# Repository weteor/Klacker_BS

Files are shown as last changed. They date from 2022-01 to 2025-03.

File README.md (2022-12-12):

# Klacker_BS
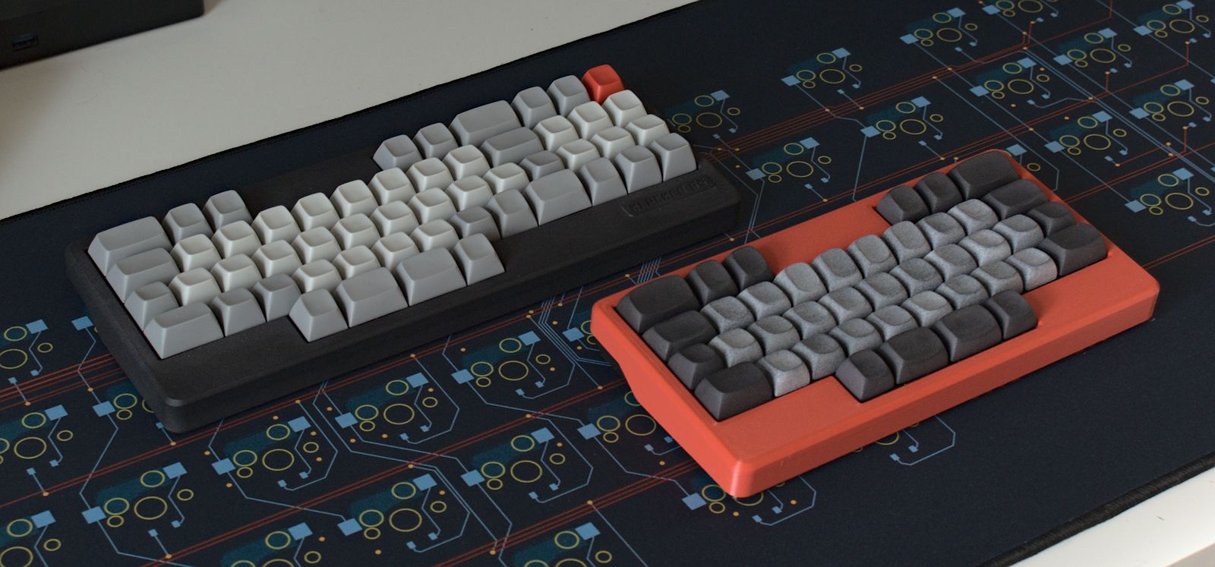
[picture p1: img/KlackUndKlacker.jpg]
klacker front


a 3x5+2 split keyboard hidden in a row staggered unibody design w/ numpad

## Features

- MX hotswap
- compact design
- layout for comfortable typing, straight wrist and minimal fingermovement
- reversable pcb w/ numpad breakoff - Layout options: Numpad Right, Left or None
- Bluetooth and USB connection 
- case files are supplied (stl, step, as well as freecad files)
- ZMK firmware support

## Layout
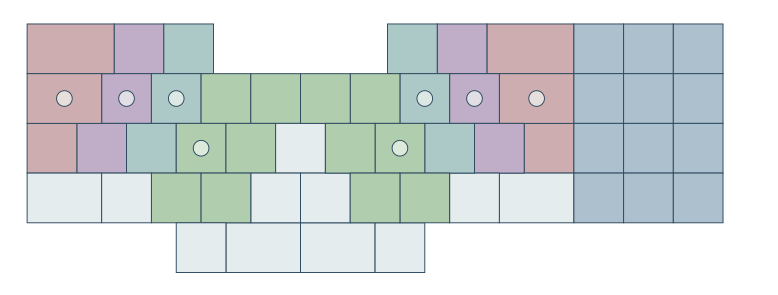
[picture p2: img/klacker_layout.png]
layout


Dots mark the home row. Colors indicate which finger is responsible for each key. It is essentially a 3x5+2 split and every keymap made for those will work on the Klacker. White keys except thumbs are free. I use the right ones as thumbkeys when I use the numpad.
It takes some time to adjust to the layout, but it is really comfortable to type on once the figers have adjusted.

## Want to build one?
You will find all production files needed to build your own [here](./prod).
I've included smt assembly files, but in the current times these might outdate quickly. If you can't figure out a replacement part, drop me a message and I will try to help out.

Case files can be found [here](./prod/case). The topside comes in two flavours. If you print at home with FDM printer, it might be better to use [prod/case/case_top_no_logo_FDM.stl](./prod/case/case_top_no_logo_FDM.stl). The top is completely flat and can be printed easily. If you use MJf or Resin use the other file

## cad data
Freecad source data for the case can be found [here](./cad_source). There are also step files if that's more helpful to you.
Plate can either be printed or made by your PCB manufacturer with the provided Kicad files.
Kicad data for plate and main pcb can be found [here](./pcb)

### firmware 
The Tipper TF uses ZMK firmware.

If you prefer the github workflow, you can find the zmk config for the Klacker BS [here](https://github.com/weteor/Klacker_BS-Config). 

## the rest
Everything in this repository is free to use however you might see fit. If you want to support me and my projects, please consider linking back to this repository if you build/change/use anything. 

If you would like to send me a tip, you could do it [here](https://ko-fi.com/weteor) (Please don't feel like you have to).

### pictures
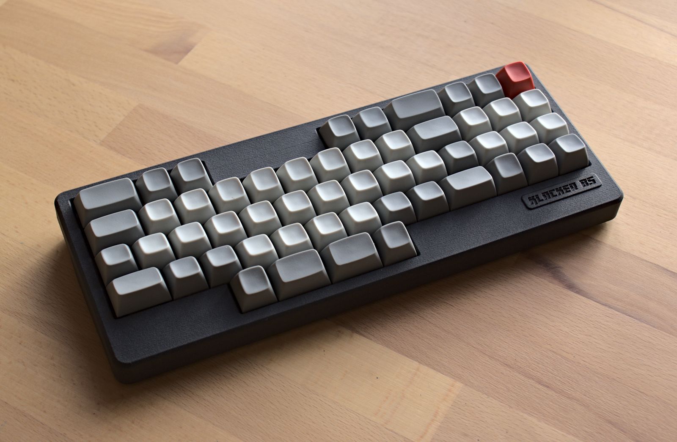
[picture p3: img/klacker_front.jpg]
klacker front

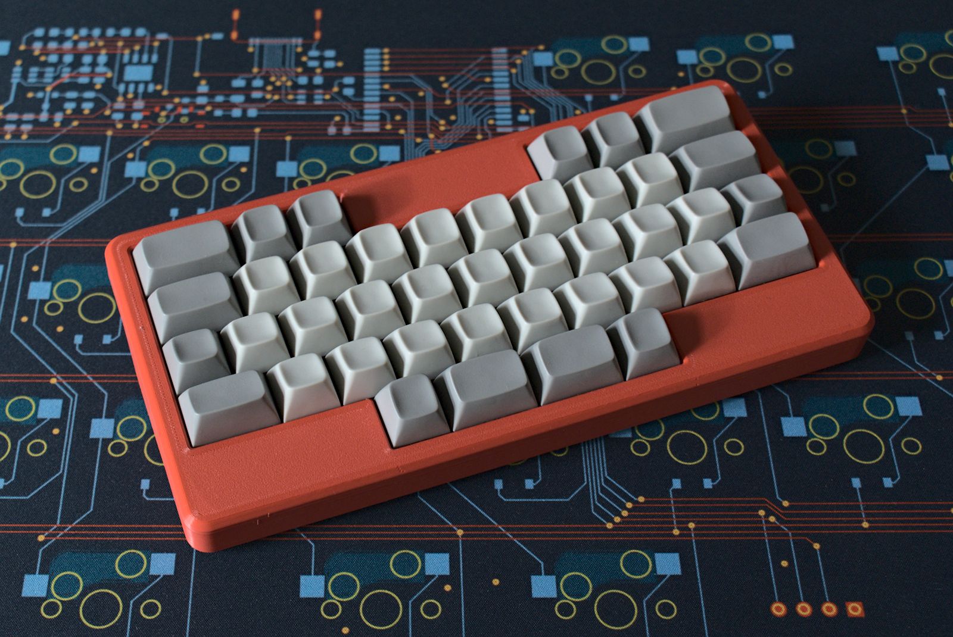
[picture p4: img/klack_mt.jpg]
klack mt

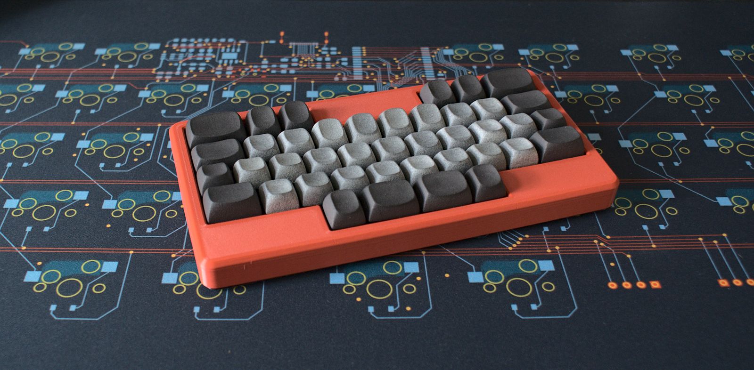
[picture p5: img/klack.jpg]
klack front


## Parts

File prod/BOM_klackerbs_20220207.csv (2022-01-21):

Comment | Designator | Footprint | LCSC
10uF | C1,C2,C10,C11 | Capacitor_SMD:C_0805_2012Metric | C15850
1nF | C4 | Capacitor_SMD:C_0805_2012Metric | C46653
4.7uF | C5,C6 | Capacitor_SMD:C_0805_2012Metric | C1779
1uF | C7,C8 | Capacitor_SMD:C_0805_2012Metric | C28323
100nF | C3,C9 | Capacitor_SMD:C_0805_2012Metric | C49678
D | D1,D2,D3,D4,D5,D6,D7,D8,D9,D10,D11,D12,D13,D14,D15,D16,D17,D18,D19,D20,D21,D22,D23,D24,D25,D26,D27,D28,D29,D30,D31,D32,D33,D34,D35,D36,D37,D38,D39,D40,D41,D42,D43,D44,D45,D46,D47,D48,D49,D50,D51,D52,D53 | weteor:D_SOD-123 | C81598
gween | D54 | Diode_SMD:D_0805_2012Metric | C2297
oragne | D55 | Diode_SMD:D_0805_2012Metric | C84256
D_Schottky_Small | D56 | Diode_SMD:D_SOD-323_HandSoldering | C172430
500mA | F1 | Fuse:Fuse_1206_3216Metric | C135336
USB_C Main | J1 | weteor:USB-C-12-Pin-MidMount | C168688
AO3401A | Q1 | Package_TO_SOT_SMD:SOT-23 | C15127
5.1k | R1,R2,R8 | Resistor_SMD:R_0805_2012Metric_Pad1.20x1.40mm_HandSolder | C27834
2M | R10 | Resistor_SMD:R_0805_2012Metric_Pad1.20x1.40mm_HandSolder | C26112
100R | R3,R11 | Resistor_SMD:R_0805_2012Metric_Pad1.20x1.40mm_HandSolder | C17408
2R2 | R12 | Resistor_SMD:R_0805_2012Metric_Pad1.20x1.40mm_HandSolder | C17521
100k | R13 | Resistor_SMD:R_0805_2012Metric_Pad1.20x1.40mm_HandSolder | C149504
1M | R4 | Resistor_SMD:R_0805_2012Metric_Pad1.20x1.40mm_HandSolder | C17514
1k | R5,R6,R7 | Resistor_SMD:R_0805_2012Metric_Pad1.20x1.40mm_HandSolder | C17513
806k | R9 | Resistor_SMD:R_0805_2012Metric_Pad1.20x1.40mm_HandSolder | C63494
SW_RESET | SW54 | weteor:Micro_Push_Button_3x6x2.5mm | C520860
TP4056 | U1 | weteor:TP4056_SOP-8-PP | C16581
DW01A | U2 | Package_TO_SOT_SMD:SOT-23-6 | C351410
USBLC6-2SC6 | U3 | Package_TO_SOT_SMD:SOT-23-6 | C2827654
FS8205 | U4 | Package_TO_SOT_SMD:SOT-23-6 | C2830320
XC6206PxxxMR-Regulator_Linear | U6 | Package_TO_SOT_SMD:SOT-23 | C5446

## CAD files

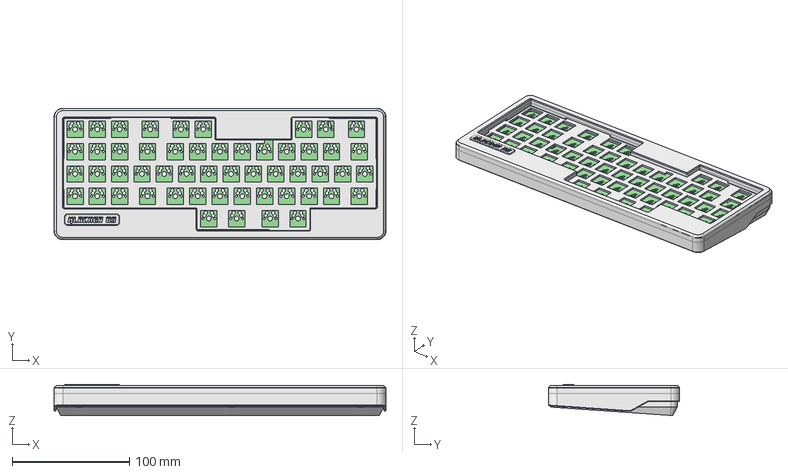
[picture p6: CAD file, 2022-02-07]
cad_source/caseNP_left.FCStd
283.7 x 112.2 x 26.6 mm
klackerM PCB
Plate (Mirror #3)

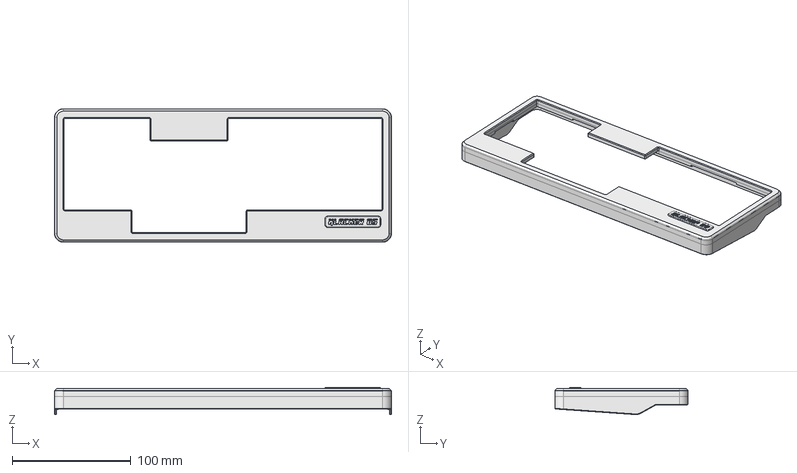
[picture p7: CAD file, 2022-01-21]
cad_source/step/CaseTop.step
283.7 x 112.2 x 22.9 mm

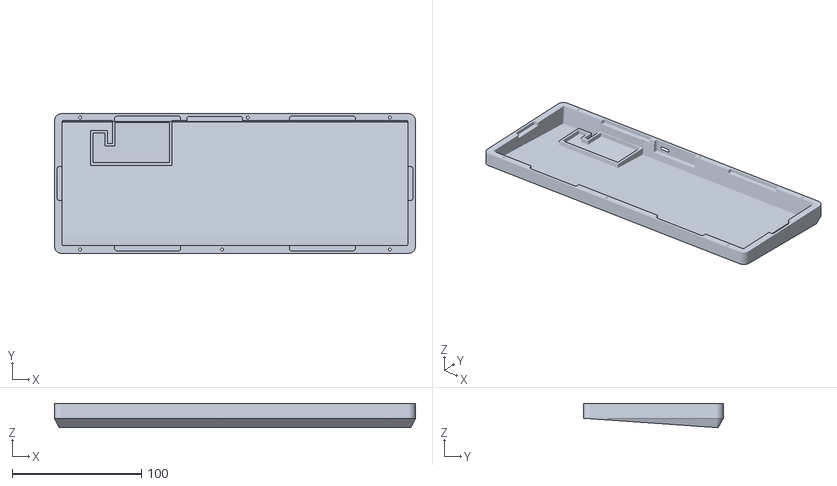
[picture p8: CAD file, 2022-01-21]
prod/__rev_1/case/case_bottom.stl
279.7 x 108.2 x 18.9

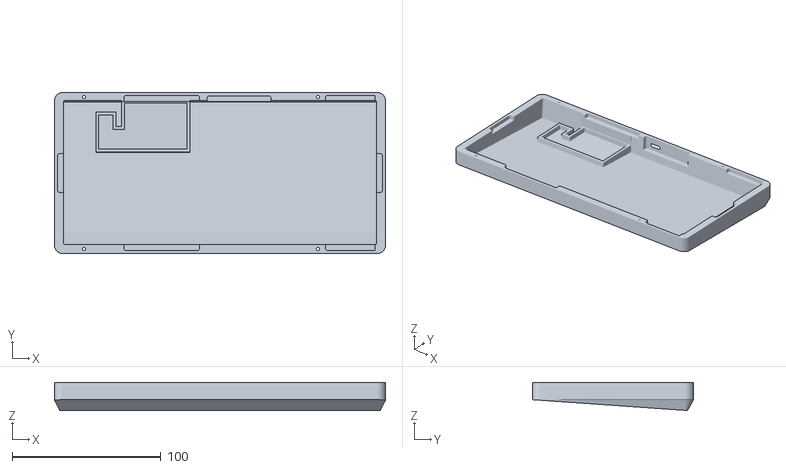
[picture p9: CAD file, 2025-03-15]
prod/case/case_noNP_bottom.stl
222.5 x 108.2 x 18.9

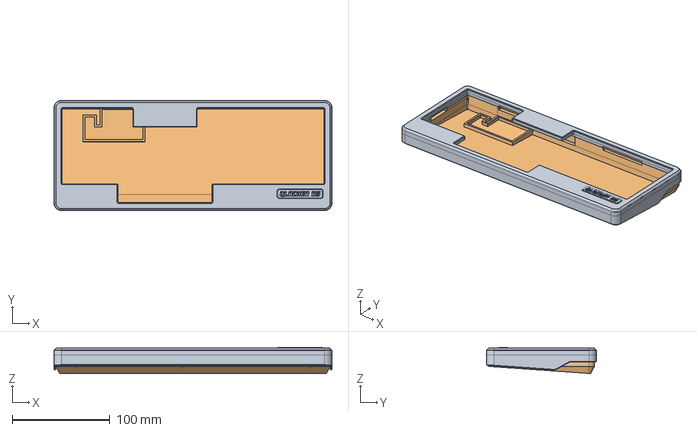
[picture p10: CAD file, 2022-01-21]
cad_source/case.FCStd
283.7 x 112.2 x 26.6 mm
CaseTop
CaseBottom

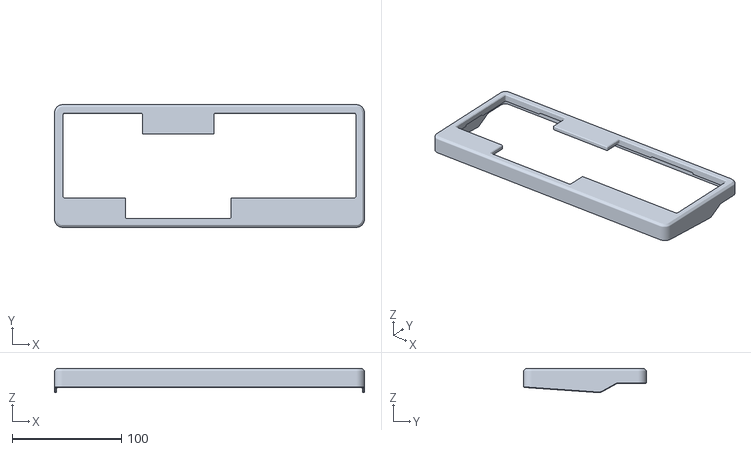
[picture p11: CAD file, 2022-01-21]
prod/__rev_1/case/case_top_no_logo_FDM.stl
283.7 x 112.2 x 22.2

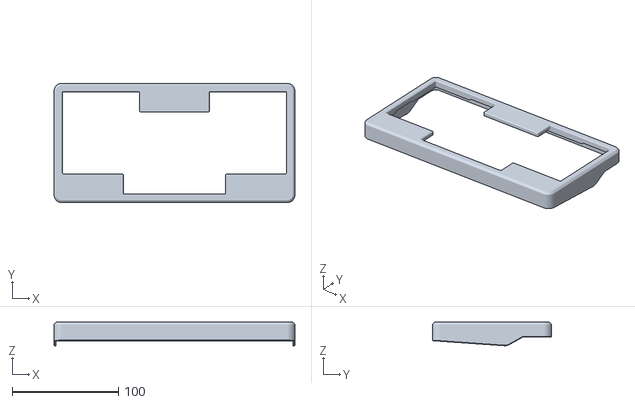
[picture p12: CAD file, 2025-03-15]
prod/case/case_noNP_top.stl
226.5 x 112.2 x 22.2

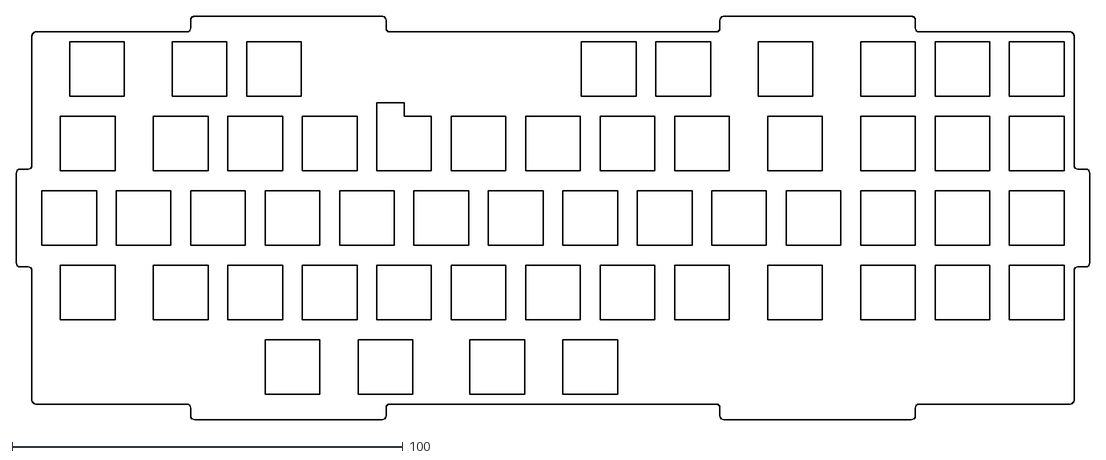
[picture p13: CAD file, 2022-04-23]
prod/case/plate.dxf
274.7 x 103.3

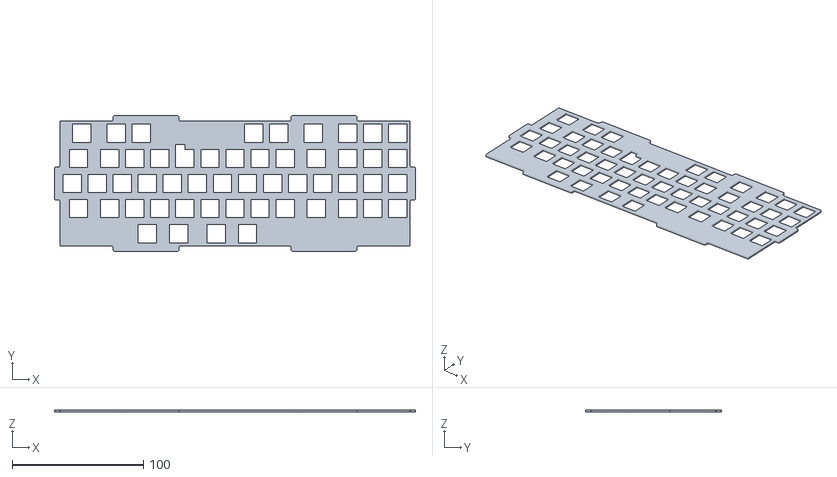
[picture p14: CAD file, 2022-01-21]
prod/__rev_1/case/plate.stl
274.7 x 103.2 x 1.60

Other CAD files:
cad_source/step/CaseBottom.step
prod/__rev_1/case/case_top.stl
prod/case/case_leftNP_bottom.stl
prod/case/case_leftNP_top.stl
prod/case/case_rightNP_bottom.stl
prod/case/case_rightNP_top.stl

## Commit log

2022-01-21 kicad files for main pcb and FR4 Plate
    [klackerM.kicad_pcb, klackerM.kicad_sch, plate.kicad_pcb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]
2022-01-21 freecad project for case
    [case.FCStd]
2022-01-21 production data, SMT Assembly and 3DP case
    [BOM_klackerM_20220102.csv, POSITION_klackerM_20220102.csv, case_bottom.stl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]
2022-01-21 add step files for case
    [CaseBottom.step, CaseTop.step]
2022-02-07 change: PCB reversable (numpad can be used left or right). Numpad can be cut off for smaller Version
    [klackerBS.kicad_sch, klackerM.kicad_pcb, klackerM.kicad_sch]
2022-02-07 add new production files
    [BOM_klackerM_20220102.csv, BOM_klackerbs_20220207.csv, POSITION_klackerM_20220102.csv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]
2022-02-07 add cad sources for Left side numpad
    [caseNP_left.FCStd]
2022-04-23 add vector plate files
    [plate.dxf]
2025-03-15 add case without numpad
    [case_noNP_bottom.stl, case_noNP_top.stl]
